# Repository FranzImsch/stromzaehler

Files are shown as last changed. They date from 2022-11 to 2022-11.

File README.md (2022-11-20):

## Hardware
Features:
- IR interface for a [smart (DE)](https://youtu.be/aqHauk3bNFA) electricity meter,
- binary input for a gas meter (impulse counter),
- high efficiency buck converter for the USB power supply.

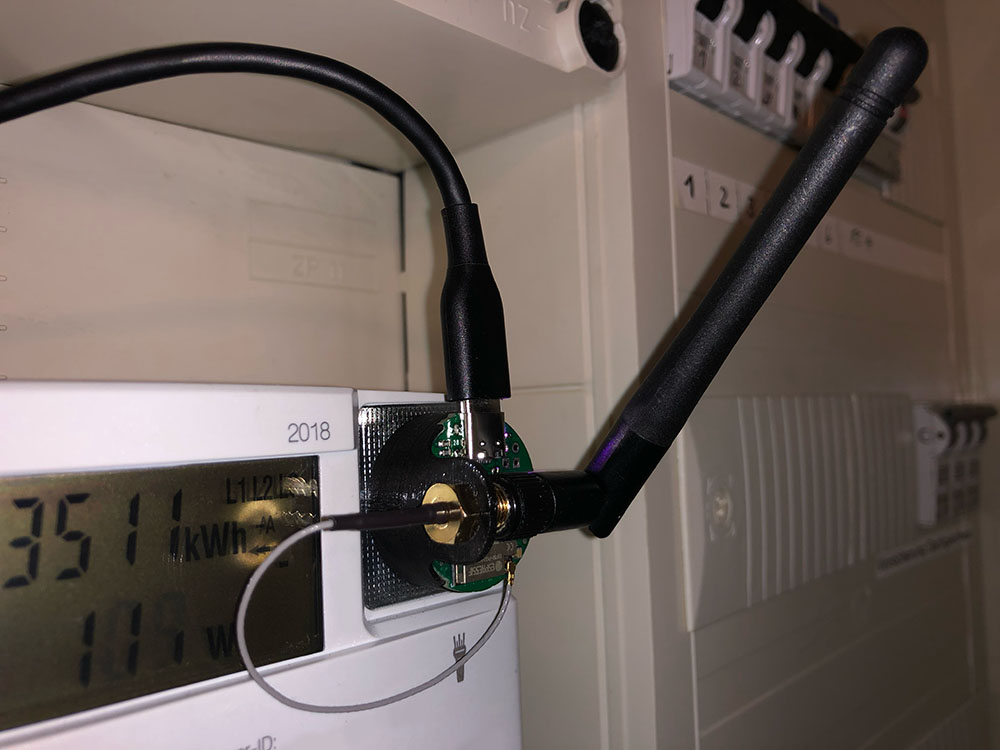
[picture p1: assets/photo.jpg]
Overview
  

The interface is mounted to the electricity meter using a ring magnet (27 x 5 x 16 mm). The magnet is glued into the 3D-printed [plastic part](https://github.com/FranzImsch/stromzaehler/blob/main/plastic_mount.step) as shown in the picture below.

A [threaded insert (M2)](https://www.digikey.de/en/products/detail/tri-star-industries-inc/M20X157C/13535373) is melted into the plastic piece so that the PCB can be mounted using an M2x5 screw.
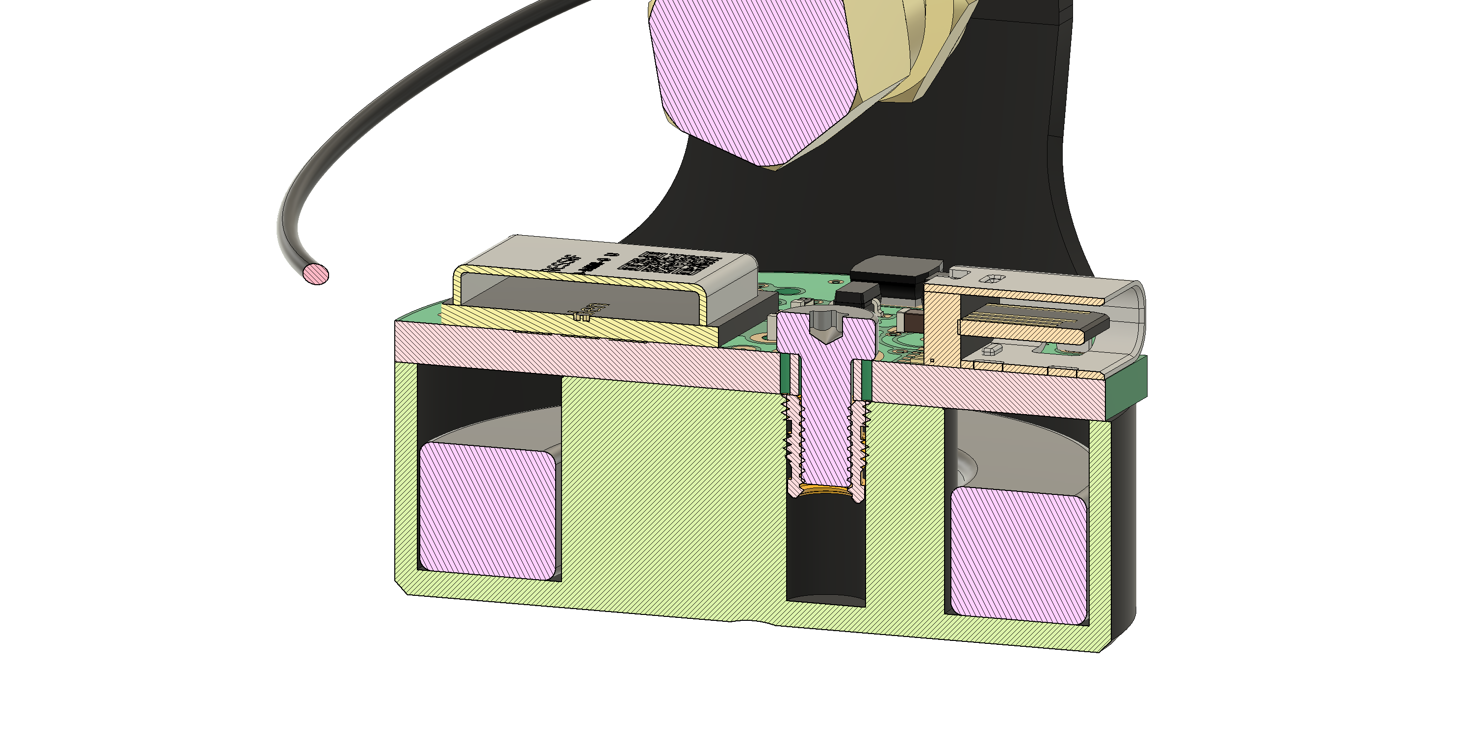
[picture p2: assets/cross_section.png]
Cross section

Detailed overview: https://a360.co/3Tq192N

Some electricity meters send data without 'request' and therefore the IR-LED along with its circuitry can be omitted in those cases. The [Volkszähler (DE)](https://wiki.volkszaehler.org/hardware/channels/meters) site is pretty useful to find information about different meters.

## Software
For Tasmota to use the SML feature, the following must be added to the ```user_config_override.h```-File (as per [documentation](https://tasmota.github.io/docs/Smart-Meter-Interface/)):

```
#ifndef USE_SCRIPT
#define USE_SCRIPT
#endif
#ifndef USE_SML_M
#define USE_SML_M
#endif
#ifdef USE_RULES
#undef USE_RULES
#endif
```
The software is compiled using the 8M tasmota32 preset. Flashed using [this](https://github.com/FranzImsch/CP2104-M8) serial adapter.

As soon as the device is connected to WiFi, the script for the electricity meter can be entered into the console (as per [documentation](https://tasmota.github.io/docs/Smart-Meter-Interface/#iskra-mt-681-sml)). The RX (25) and TX (26) GPIOs have to be adjusted. The script might need to be adjusted for the very meter that is used. For that, [this](https://tasmota-sml-parser.azurewebsites.net/) tool was tremendously helpful.

The **gas meter** is read with a reed contact. IO27 is set as a counter in Tasmota. What 1 Tick corresponds to in terms of gas is usually written somewhere on the meter. The counter is debounced using the [```CounterDebounce 250```](https://tasmota.github.io/docs/Commands/#sensors) command (which corresponds to 250 ms debounce time).

Also, the TelePeriod was set to 10 seconds (the fastest) as per [documentation](https://tasmota.github.io/docs/Commands/#mqtt).

## Links
- [3D model](https://a360.co/3Tq192N)  
- [Schematic](https://franz.science/stromzaehler/KiCad-Files/Schematic.pdf)  
- [iBom](https://franz.science/stromzaehler/ibom/)  
- [Tasmota](https://github.com/arendst/tasmota)

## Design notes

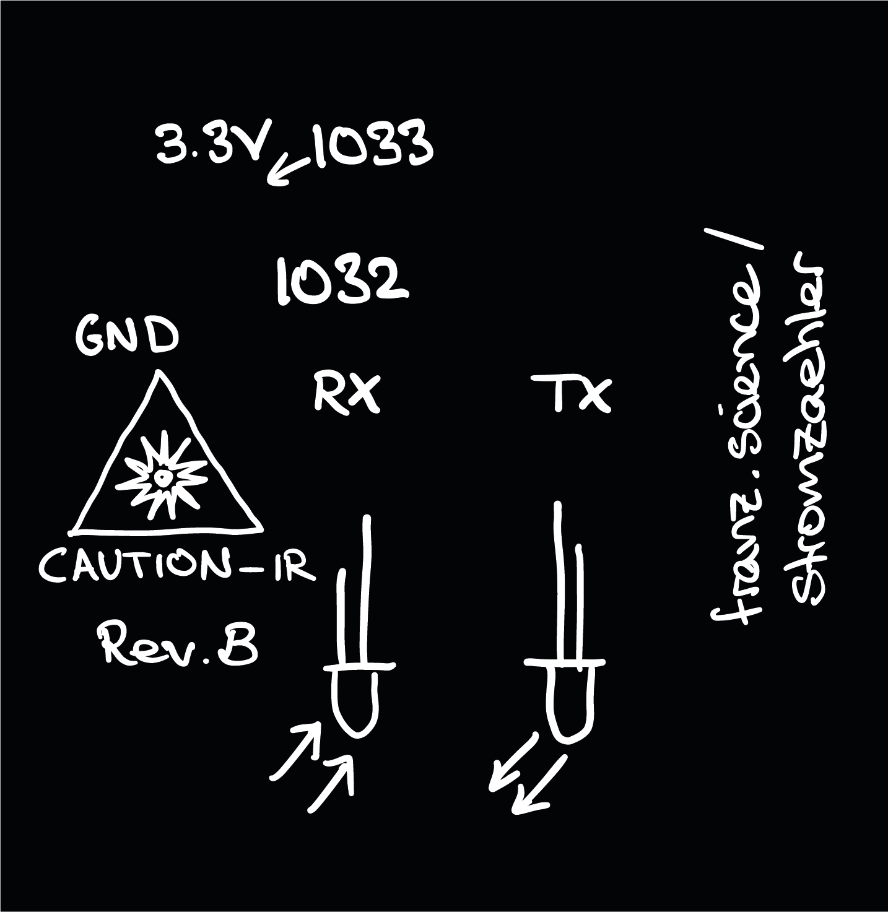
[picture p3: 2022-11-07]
KiCad-Files/Silkscreen/silkscreen-back.png

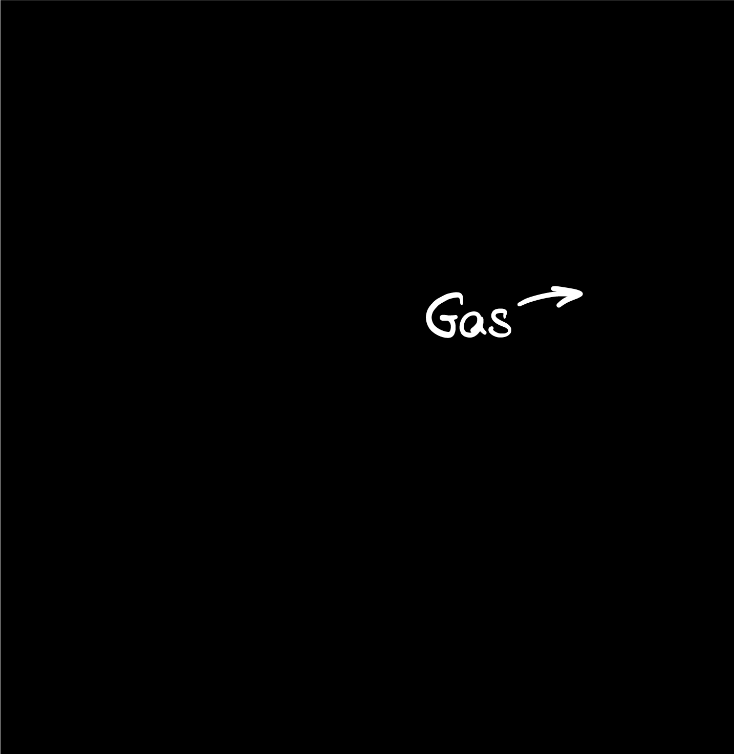
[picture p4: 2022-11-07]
KiCad-Files/Silkscreen/silkscreen-front.png

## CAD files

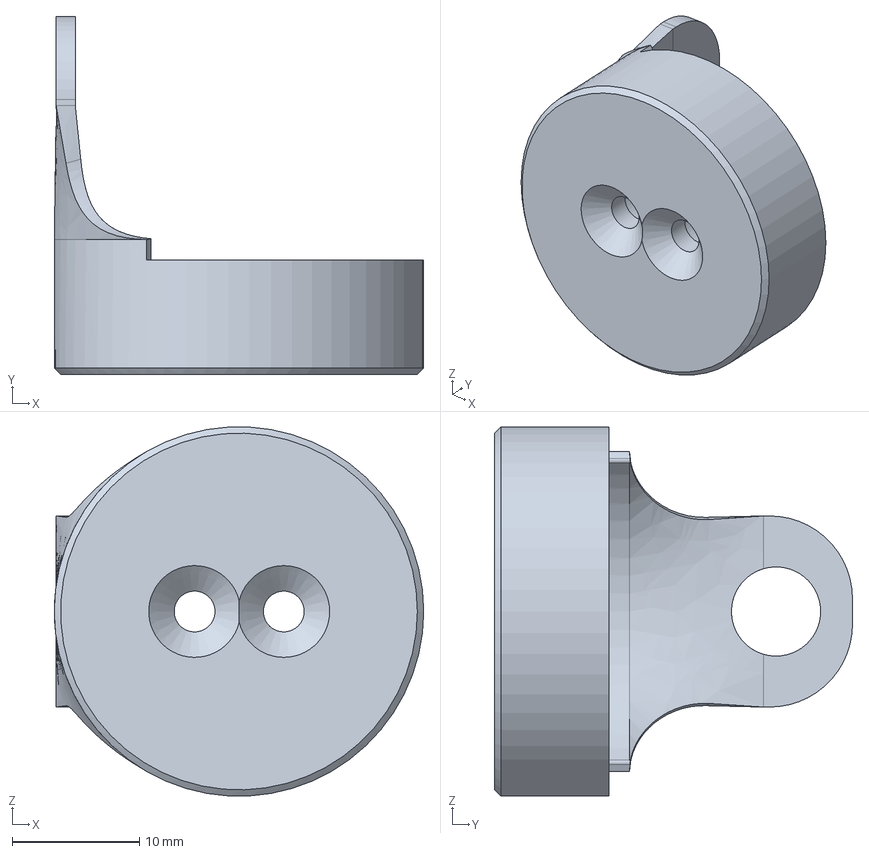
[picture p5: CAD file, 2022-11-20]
plastic_mount.step
29.0 x 28.1 x 29.0 mm

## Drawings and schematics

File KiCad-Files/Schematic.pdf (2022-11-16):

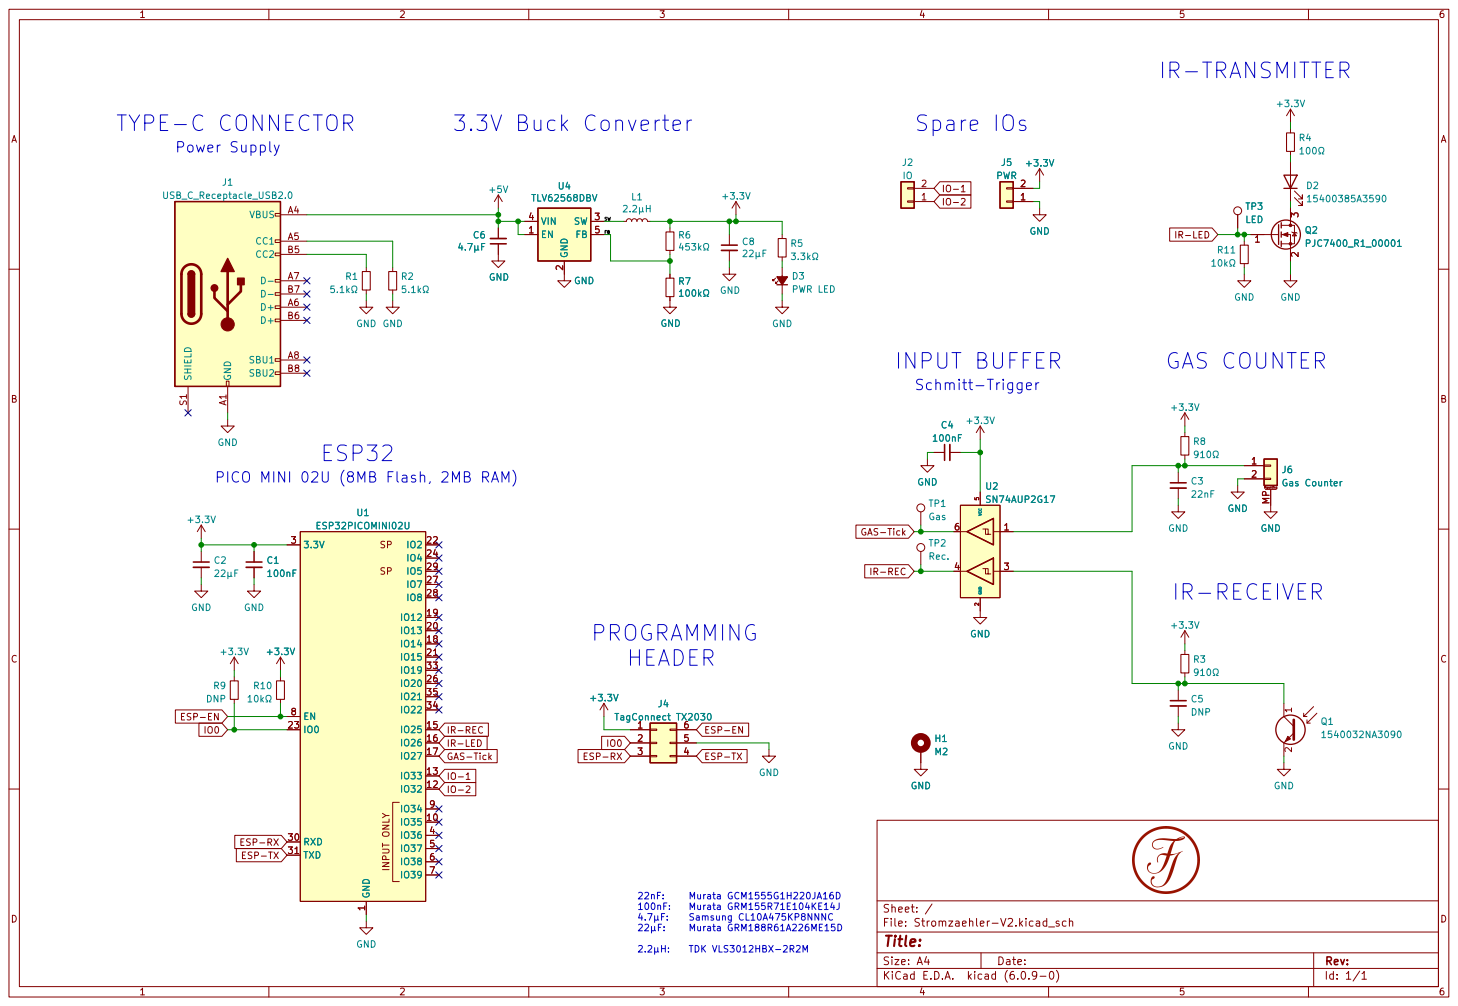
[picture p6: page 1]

2 SW 3 VIN 4 FB 5 GND GND

PICO MINI 02U (8MB Flash, 2MB RAM)

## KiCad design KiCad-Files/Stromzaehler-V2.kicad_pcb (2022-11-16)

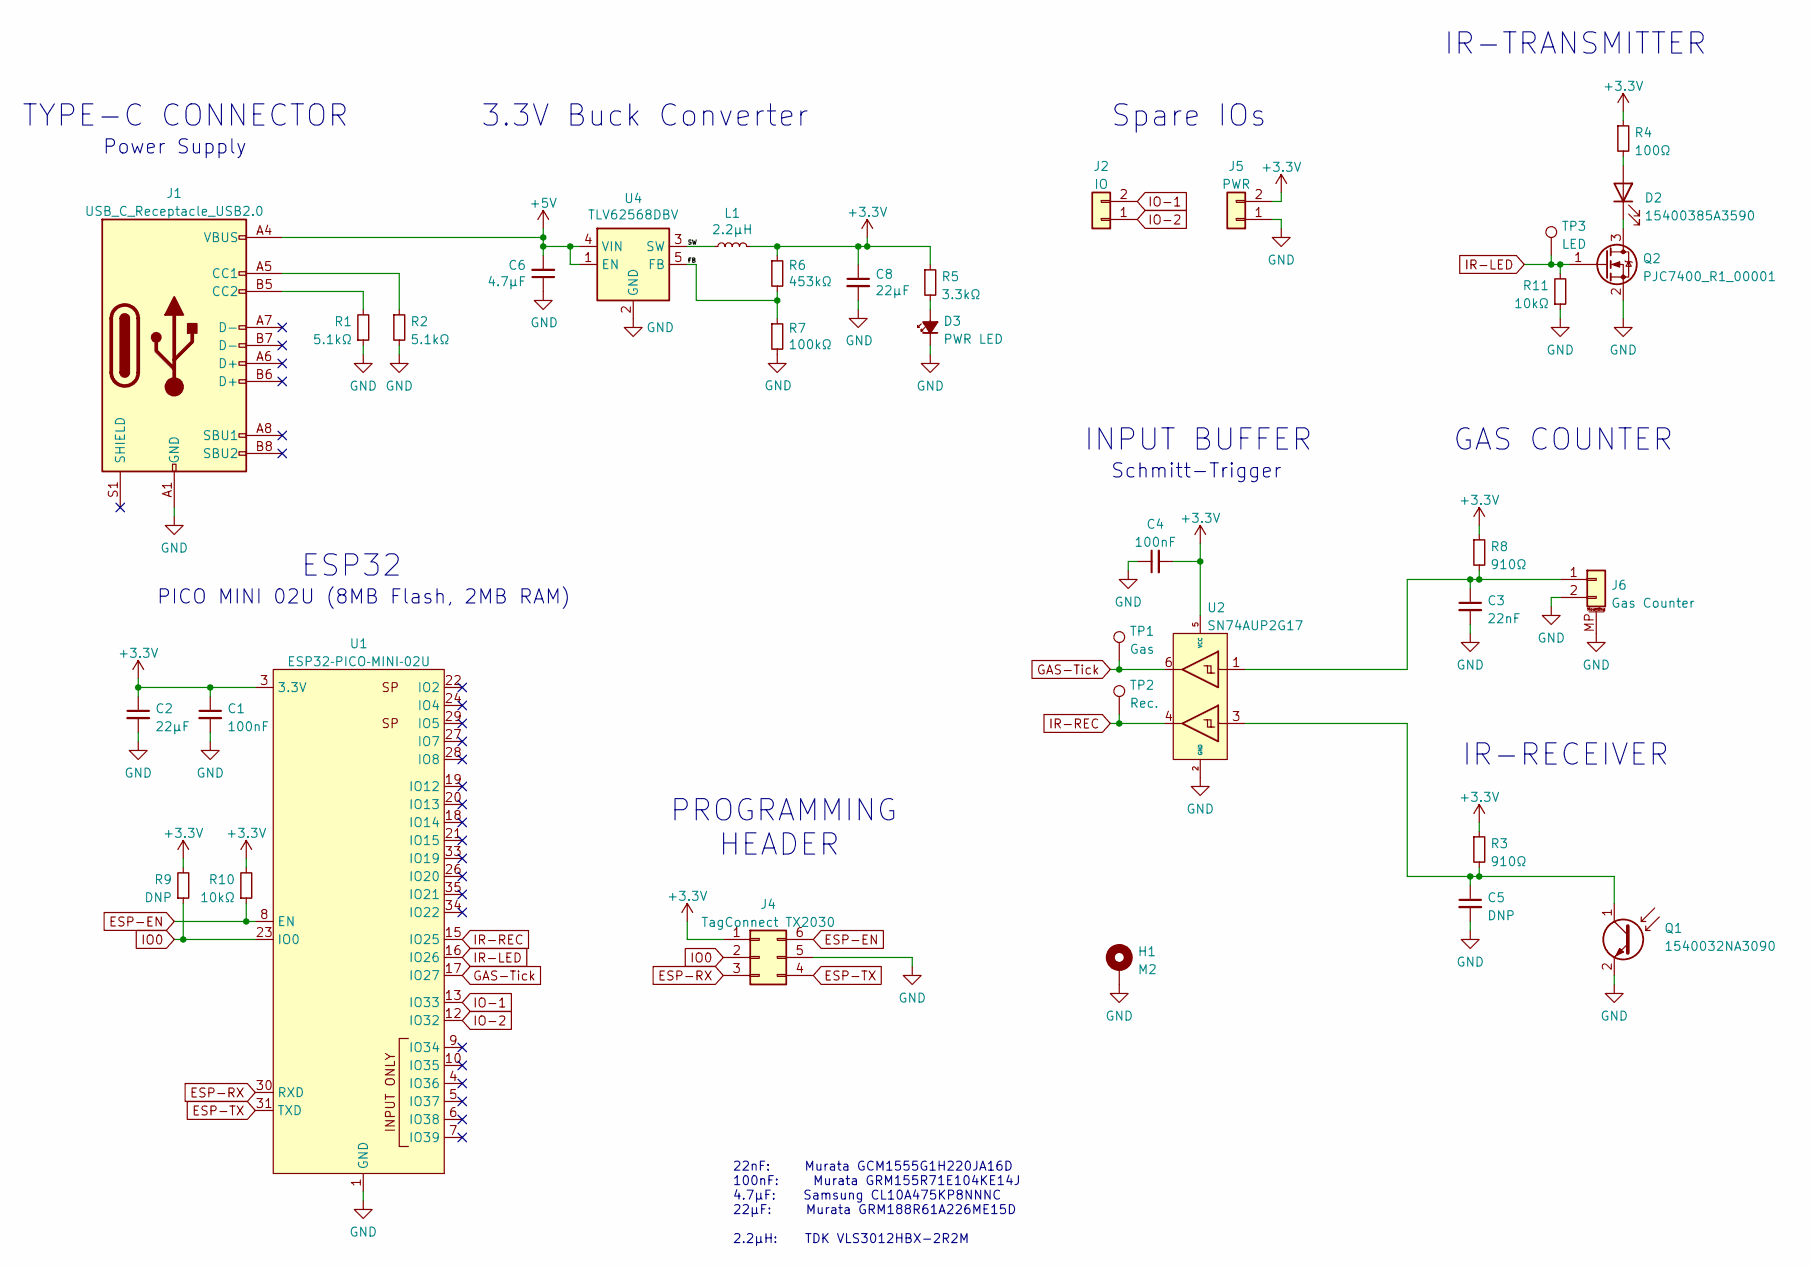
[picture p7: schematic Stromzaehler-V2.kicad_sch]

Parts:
C1, C4: 100nF; C_0402_1005Metric_NoSilk
C2, C8: 22µF; C_0603_1608Metric_NoSilk
C3: 22nF; C_0402_1005Metric_NoSilk
C5: DNP; C_0402_1005Metric_NoSilk_DNP
C6: 4.7µF; C_0603_1608Metric_NoSilk
D2: 15400385A3590; LED_D3.0mm_IRBlack_NoSillk
D3: PWR LED; LED_0603_1608Metric_SmallSilk
H1: M2; MountingHole_2.2mm_M2_Pad_Via_NoSilk
J1: USB_C_Receptacle_USB2.0; USB_C_Receptacle_C313131_TYPE-C-31-M-12
J2: IO; PinHeader_1x02_P2.54mm_Vertical_NoSilk
J4: TagConnect TX2030; Tag-Connect_TC2030-IDC-NL_2x03_P1.27mm_Vertical_NoSilk
J5: PWR; PinHeader_1x02_P2.54mm_Vertical_NoSilk
J6: Gas Counter; JST_SH_SM02B-SRSS-TB_1x02-1MP_P1.00mm_Horizontal_NoSilk
L1: 2.2µH; L_Wuerth_MAPI-3012_NoSilk
Q1: 1540032NA3090; LED_D3.0mm_IRBlack_NoSillk
Q2: PJC7400_R1_00001; SOT-323_SC-70_NoSilk
R1, R2: 5.1kΩ; R_0402_1005Metric_NoSilk
R3, R8: 910Ω; R_0402_1005Metric_NoSilk
R4: 100Ω; R_0603_1608Metric_NoSilk
R5: 3.3kΩ; R_0402_1005Metric_NoSilk
R6: 453kΩ; R_0603_1608Metric_NoSilk
R7: 100kΩ; R_0603_1608Metric_NoSilk
R9: DNP; R_0402_1005Metric_NoSilk_DNP
R10, R11: 10kΩ; R_0402_1005Metric_NoSilk
TP1: Gas; TestPoint_Pad_D1.0mm_NoSIlk
TP2: Rec.; TestPoint_Pad_D1.0mm_NoSIlk
TP3: LED; TestPoint_Pad_D1.0mm_NoSIlk
U1: ESP32­PICO­MINI­02U; ESP32-PICO-MINI-02U
U2: SN74AUP2G17; SOT-363_SC-70-6_NoSilk
U4: TLV62568DBV; SOT-23-5_NoSilk

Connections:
+3.3V: C1.1, C2.1, C4.2, C8.1, J4.1, J5.2, L1.2, R3.1, R4.1, R5.1, R6.1, R8.1, R9.2, R10.2, U1.3 (3.3V), U2.5 (VCC)
+5V: C6.2, J1.A4 (VBUS), J1.A9 (VBUS), J1.B4 (VBUS), J1.B9 (VBUS), U4.1 (EN), U4.4 (VIN)
/FB: R6.2, R7.1, U4.5 (FB)
/SW: L1.1, U4.3 (SW)
ESP-EN: J4.6, R10.1, U1.8 (EN)
ESP-RX: J4.3, U1.30 (RXD)
ESP-TX: J4.4, U1.31 (TXD)
GAS-Tick: TP1.1, U1.17 (IO27), U2.6
GND: C1.2, C2.2, C3.2, C4.1, C5.2, C6.1, C8.2, D3.1 (K), H1.1, J1.A1 (GND), J1.A12 (GND), J1.B1 (GND), J1.B12 (GND), J4.5, J5.1, J6.2, J6.MP (MountPin), Q1.2 (E), Q2.2 (S), R1.1, R2.2, R7.2, R11.1, U1.1 (GND), U1.2 (GND), U1.11 (GND), U1.14 (GND), U1.49 (GND), U2.2 (GND), U4.2 (GND)
IO0: J4.2, R9.1, U1.23 (IO0)
IO-1: J2.2, U1.13 (IO33)
IO-2: J2.1, U1.12 (IO32)
IR-LED: Q2.1 (G), R11.2, TP3.1, U1.16 (IO26)
IR-REC: TP2.1, U1.15 (IO25), U2.4
unnamed: C3.1, J6.1, R8.2, U2.1
unnamed: C5.1, Q1.1 (C), R3.2, U2.3
unnamed: D2.1 (K), Q2.3 (D)
unnamed: D2.2 (A), R4.2
unnamed: D3.2 (A), R5.2
unnamed: J1.A5 (CC1), R2.1
unnamed: J1.B5 (CC2), R1.2

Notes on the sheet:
INPUT BUFFER
Spare IOs
GAS COUNTER
22nF: Murata GCM1555G1H220JA16D 100nF: Murata GRM155R71E104KE14J 4.7µF: Samsung CL10A475KP8NNNC 22µF: Murata GRM188R61A226ME15D 2.2µH: TDK VLS3012HBX-2R2M
Schmitt-Trigger
PICO MINI 02U (8MB Flash, 2MB RAM)
3.3V Buck Converter
TYPE-C CONNECTOR
Power Supply
ESP32
PROGRAMMING HEADER
IR-RECEIVER
IR-TRANSMITTER

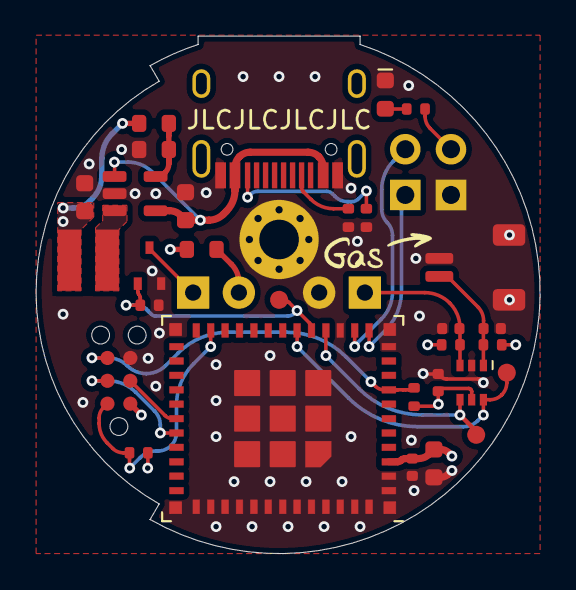
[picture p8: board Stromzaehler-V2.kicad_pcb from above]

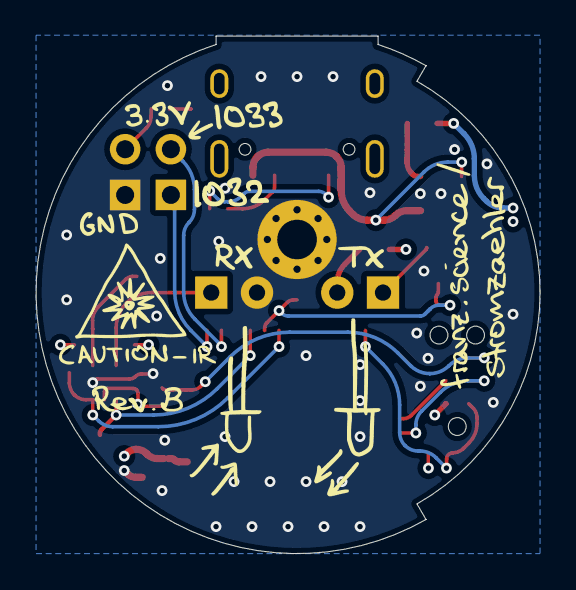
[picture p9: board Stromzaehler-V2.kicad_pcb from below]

Board: 4 copper layers, 28.0 x 28.7 mm, 35 parts (2 on the bottom side), 21 nets.

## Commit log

2022-11-07 added kicad files
    [Stromzaehler-V2.kicad_pcb, Stromzaehler-V2.kicad_sch]
2022-11-16 finished testing device
    [Stromzaehler-V2.kicad_pcb, Stromzaehler-V2.kicad_sch]
2022-11-20 enhanced readme
    [plastic_mount.step]
